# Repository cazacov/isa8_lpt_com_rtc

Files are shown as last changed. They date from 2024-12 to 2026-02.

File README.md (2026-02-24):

# ISA8 LPT COM RTC

An 8-bit ISA expansion card providing a parallel port, two serial ports, and a battery-backed real-time clock for retro PC/XT systems.

The card was designed with a help of GitHub Copilot.

## Prototype
See [prototype.md](./prototype.md) - Learn how to decode address, control RTC chip and design GAL firmware.
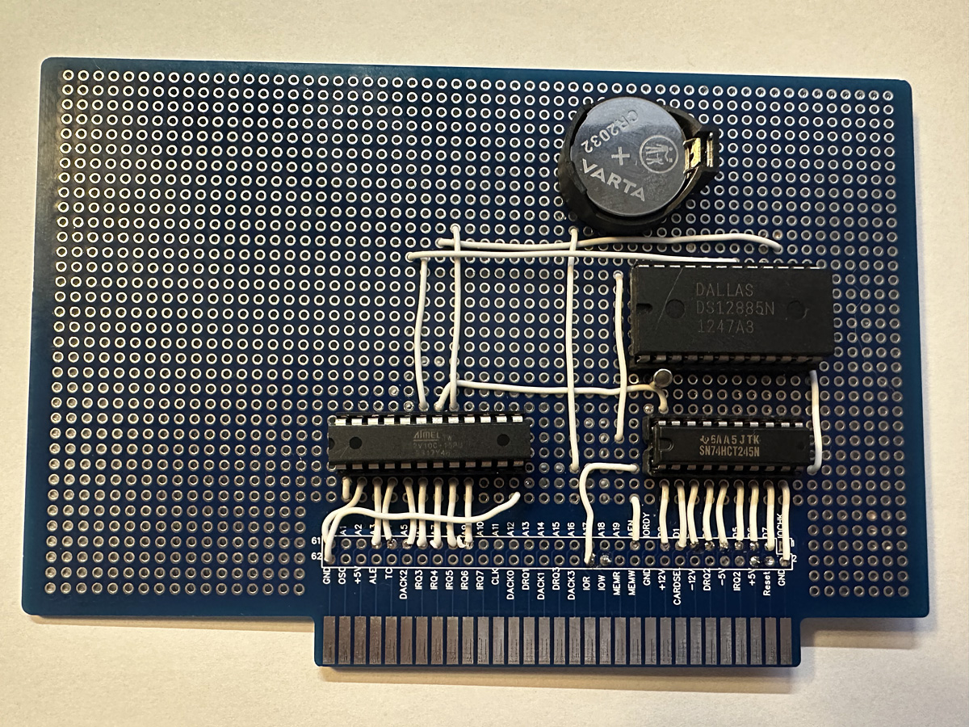
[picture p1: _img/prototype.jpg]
Prototype

Vibe soldering with LLM.

## Features

- **Parallel Port (PRN)** — UM82C11-C, DB-25 connector, Centronics-compatible
- **2 × Serial Port (COM)** — 16450/16550-compatible UARTs, RS-232 levels via GD75232N
- **Real-Time Clock (RTC)** — DS12885 with CR2032 battery backup and CMOS RAM
- **Single-chip address decoding** — ATF22V10 PLD, no additional logic gates
- **Fully jumper-configurable** — port addresses and IRQs
- **Socket-based device enable/disable** — devices disabled by removing chip from socket; 10k pull-up resistor network on data bus ensures clean 0xFF reads for empty sockets

## Target Systems

- IBM PC/XT and compatibles (8088/8086)
- Compatible with [8088 BIOS](https://github.com/skiselev/8088_bios)
- DOS and early Windows

## Design Specifications

### ISA Bus Interface

- 8-bit data bus (D0–D7)
- Standard ISA 8-bit (62-pin) edge connector
- +5 V, +12 V, −12 V power rails from bus

### Parallel Port (PRN)

- UM82C11-C printer adapter interface chip
- DB-25 connector, standard Centronics-compatible
- Configurable base address: 0x378 (LPT1) or 0x278 (LPT2)
- Configurable interrupt: IRQ7 or IRQ5
- Active-low chip select: PRN_CS#

### Serial Ports (UART)

Both ports use 16450/16550-compatible UARTs with RS-232 level shifting (GD75232N or equivalent). CS0 and CS1 are tied to GND; CS2 is the active-low chip select driven by the PLD.

| Port | Connector | Base Address Options | IRQ Options | CS Signal |
|---|---|---|---|---|
| COM1 | DB-9 | 0x3F8 or 0x2F8 | IRQ4 or IRQ3 | COM1_CS# |
| COM2 | 2×5 header | 0x3E8 or 0x2E8 | IRQ4 or IRQ3 | COM2_CS# |

### Real-Time Clock (RTC)

- DS12885 RTC chip with CMOS RAM for BIOS settings
- CR2032 battery backup
- Fixed I/O ports 0x70 (address) / 0x71 (data)
- Intel bus timing (MOT pin left unconnected; internal 20kΩ pull-down selects Intel mode)
- Configurable interrupt: IRQ2/9, IRQ5, IRQ6, or IRQ7
- IRQ polarity inversion: DS12885 IRQ output is active-low open-drain; an NPN transistor (Q1, 2N3904) with a 330Ω series current-limiting resistor converts it to the active-high signal expected by the ISA bus 8259A PIC (see [design.md](design.md) Section 6 for circuit details)
- On PC/XT (single 8259A), the IRQ2 jumper position triggers IRQ2 (INT 0Ah); on AT-class systems (cascaded 8259A), the same physical IRQ2 line is routed to the slave PIC as IRQ9 (INT 71h), which the BIOS redirects to INT 0Ah for compatibility
- Multiplexed address/data bus: CPU writes register address to port 0x70, then reads/writes data at port 0x71 (see [design.md](design.md) Section 5 for interface details, timing diagrams, and PLD equations)

### Oscillators

| Ref | Frequency | Purpose |
|-----|---|---|
| Y1 | 32.768 kHz | RTC crystal |
| Y2 | 1.8432 MHz | UART clock oscillator |

### Data Bus Buffering

A 74HCT245 bidirectional transceiver decouples all peripheral data pins from the ISA bus:

- **ISA side** (A1–A8, pins 2–9) — connected to ISA D0–D7
- **Card side** (B1–B8, pins 11–18) — connected to RTC, UART, and PRN data pins; 8×10k pull-up resistor network to VCC ensures defined HIGH state when no device drives the bus (empty sockets read as 0xFF)
- **DIR** — connected to IOR# (IOR#=0 → B-to-A read; IOR#=1 → A-to-B write)
- **G#** — active-low enable driven by ATF22V10

### Address Decoding

A single ATF22V10 PLD decodes all port addresses and generates chip-select signals for every peripheral, plus the bus buffer enable and the RTC address strobe. No additional logic gates are required. Jumper inputs to the PLD allow per-device address and enable configuration.

See [design.md](design.md) for detailed PLD equations, pin assignments, and CUPL source.

### Jumper Configuration

#### Address Selection (3-pin headers: VCC / signal / GND)

| Jumper | Cap 1-2 (HIGH) | Cap 2-3 (LOW) |
|---|---|---|
| J1 (COM1 Addr) | 0x3F8 (COM1) | 0x2F8 (COM2) |
| J3 (COM2 Addr) | 0x3E8 (COM3) | 0x2E8 (COM4) |
| J5 (PRN Addr) | 0x378 (LPT1) | 0x278 (LPT2) |

#### IRQ Selection (3-pin headers)

| Jumper | Position 1 | Position 2 |
|---|---|---|
| J2 (COM1 IRQ) | IRQ4 | IRQ3 |
| J4 (COM2 IRQ) | IRQ4 | IRQ3 |
| J6 (PRN IRQ) | IRQ7 | IRQ5 |
| J7 (RTC IRQ) | IRQ2/9 / IRQ5 / IRQ6 / IRQ7 (1×5 header) | — |

#### RTC CMOS Clear

J8 is a 2-pin header connected between DS12885 RCLR# (pin 21) and GND. The RCLR# pin has an internal pull-up inside the DS12885. Momentarily shorting J8 with a jumper cap (while the system is powered off) clears all CMOS RAM and RTC registers to defaults.

#### Device Enable/Disable

Devices are enabled/disabled by installing or removing the chip from its DIP socket. A 10k×8 pull-up resistor network on the 74HCT245 B-side ensures that empty sockets read as 0xFF, which is the expected response for absent I/O devices. Software detection (e.g., BIOS UART scratch register test) correctly identifies the device as absent.

The RTC is always enabled (no disable mechanism).

## Manufacturing Notes

- **Board thickness:** 1.6 mm
- **Copper weight:** 1 oz (35 μm)
- **Surface finish:** HASL or ENIG
- **Solder mask / silkscreen:** any color; white silkscreen on top
- **Components:** through-hole
- **Form factor:** standard ISA 8-bit card dimensions
- **Connectors:** bracket-mounted DB-25 and DE-9; CR2032 battery holder

## Getting Started

### Required Software

- [KiCad](https://www.kicad.org/) 9.0 or later
- [GALasm](https://github.com/daveho/GALasm) to compile firmware
- A PLD programmer (e.g. TL866II+) for the ATF22V10
- Git

### Opening the Project

1. Clone the repository
2. Open `KiCad/V2/ISA8_LPT_COM_RTC.kicad_pro` in KiCad
3. Schematic: `KiCad/V2/ISA8_LPT_COM_RTC.kicad_sch`
4. PCB layout: `KiCad/V2/ISA8_LPT_COM_RTC.kicad_pcb`

### Testing

1. Visually inspect for solder bridges; continuity-test power rails
2. Install card in an ISA slot
3. Verify I/O port addressing with DEBUG or a diagnostic utility
4. Test serial ports with a loopback plug or terminal program
5. Test parallel port with a printer or loopback connector
6. Verify RTC keeps time after power-off (battery backup)
7. Confirm interrupt operation for each device

## KiCad

Third party libraries should be stored in locations referenced with environment variables:
- **KICADLIB_SKISELEV** [Sergey Kiselev's library](https://github.com/skiselev/my_kicad_library)
- **KICADLIB_VICTOR** [Victor's (my) library](https://github.com/cazacov/VictorLib)

## Troubleshooting

| Symptom | Check |
|---|---|
| Card not detected | ISA slot seating, power rails |
| Address conflicts | Reconfigure base address jumpers, ensure ATF22V10 firmware is programmed properly |
| IRQ conflicts | Change IRQ jumper settings |
| RTC loses time | Replace CR2032 battery |
| Serial errors | Baud rate, RS-232 cable/levels |
| Parallel port issues | Cable, port mode |

## Project Files

| File | Description |
|---|---|
| `KiCad/V2/ISA8_LPT_COM_RTC.kicad_pro` | KiCad project |
| `KiCad/V2/ISA8_LPT_COM_RTC.kicad_sch` | Schematic |
| `KiCad/V2/ISA8_LPT_COM_RTC.kicad_pcb` | PCB layout |
| `design.md` | Implementation plan — PLD equations, pin maps, CUPL source |
| `pld/ISA8_DECODE.pld` | CUPL source for ATF22V10 |
| `pld/ISA8_DECODE.jed` | Compiled JEDEC fuse map |

## Datasheets

- [DS12885 / DS12C887A (RTC)](https://www.analog.com/media/en/technical-documentation/data-sheets/DS12885-DS12C887A.pdf)

## Version History

| Version | Notes |
|---|---|
| V2 | Current design iteration |
| V1 | Initial design (see `KiCad/V1/`) |

## Contributing

1. Document all schematic changes
2. Update PCB layout accordingly
3. Run DRC and ERC in KiCad
4. Update documentation as needed

## Credits

- [Sergey Kiselev's projects](https://github.com/skiselev)
- [Aitor Gómez García's RTC8088 project](https://github.com/spark2k06/RTC8088)

## License

MIT

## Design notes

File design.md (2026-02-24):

# ISA8 LPT COM RTC - Implementation Plan

## 1. ISA Bus Signals Used

| ISA Signal | Direction | Purpose |
|---|---|---|
| D0-D7 | Bidir | Data bus (active via 74245) |
| A0-A9 | In | Address bus (only A0-A9 needed, highest port 0x3F8 = 0b11_1111_1000; A2 also used for precise RTC decode) |
| AEN | In | DMA cycle indicator. Must be LOW for valid CPU I/O cycle |
| IOR# | In | I/O Read strobe (active low) |
| IOW# | In | I/O Write strobe (active low) |
| IRQ3-IRQ7 | Out | Interrupt request lines (active high) |

## 2. I/O Port Address Map

| Device | Option A (Default) | Option B | Address Range Size |
|---|---|---|---|
| COM1 | 0x3F8-0x3FF | 0x2F8-0x2FF | 8 bytes |
| COM2 | 0x3E8-0x3EF | 0x2E8-0x2EF | 8 bytes |
| PRN  | 0x378-0x37F (LPT1) | 0x278-0x27F (LPT2) | 8 bytes |
| RTC | 0x70-0x71 | (fixed) | 2 bytes |

### Address Bit Patterns (A9..A0)

```
COM1 @ 0x3F8:  11 1111 1xxx    COM1 @ 0x2F8:  10 1111 1xxx
COM2 @ 0x3E8:  11 1110 1xxx    COM2 @ 0x2E8:  10 1110 1xxx
PRN   @ 0x378:  11 0111 1xxx    PRN   @ 0x278:  10 0111 1xxx
RTC   @ 0x070:  00 0111 00 0x   (fixed, no jumper; A2 checked by PLD)
```

Note: `x` bits are don't-care for chip-select (decoded internally by each device via A0-A2). For the RTC, A0 and A2 are checked by the PLD; A1 is not checked (mirroring at 0x72/0x73 only — unused addresses on any standard PC).

## 3. Jumper Design

### 3.1 Jumper Inputs to ATF22V10

Instead of feeding raw address lines and muxing them inside the PLD, use jumpers to route one of two address lines to a single PLD input. This minimizes PLD pin usage.

The key observation: for each device pair, only **one address bit** changes between Option A and Option B — and that bit is always **A8**:

| Device | Option A | Option B | Differing Bit |
|---|---|---|---|
| COM1 | 0x3F8 (A8=1) | 0x2F8 (A8=0) | A8 |
| COM2 | 0x3E8 (A8=1) | 0x2E8 (A8=0) | A8 |
| PRN | 0x378 (A8=1) | 0x278 (A8=0) | A8 |

All three devices have A9=1 for both address options. Each device needs its own jumper input to the PLD for independent address configuration.

**Approach: one jumper bit per device fed into the PLD.**

- **J_COM1**: 1-bit jumper (HIGH = 0x3F8, LOW = 0x2F8)
- **J_COM2**: 1-bit jumper (HIGH = 0x3E8, LOW = 0x2E8)
- **J_PRN**: 1-bit jumper (HIGH = 0x378, LOW = 0x278)

These jumper signals connect directly to ATF22V10 inputs. The PLD equations incorporate them.

### 3.2 IRQ Selection Jumpers

IRQ routing does NOT go through the PLD. Use simple 3-pin jumper headers connecting each device's IRQ output to the selected ISA IRQ line.

| Jumper | Position 1 | Position 2 | Notes |
|---|---|---|---|
| J_IRQ_COM1 | IRQ4 | IRQ3 | Standard COM1=IRQ4, COM2=IRQ3 |
| J_IRQ_COM2 | IRQ4 | IRQ3 | Standard COM3=IRQ4, COM4=IRQ3 |
| J_IRQ_PRN | IRQ7 | IRQ5 | Standard LPT1=IRQ7, LPT2=IRQ5 |
| J_IRQ_RTC | IRQ2/9 / IRQ5 / IRQ6 / IRQ7 | — | 5-pin header, jumper selects one of 4 |

For the RTC IRQ (4 choices: IRQ2/9, IRQ5, IRQ6, IRQ7), use a 1×5 pin header:
```
Pin 1: RTC_IRQ_OUT (from Q1 collector via R4, active high — inverted from DS12885)
Pin 2: IRQ2 (= IRQ9 on AT-class machines via cascade)
Pin 3: IRQ5
Pin 4: IRQ6
Pin 5: IRQ7
```
A single jumper wire connects Pin 1 to one of Pins 2–5.

**Note:** On PC/XT systems (single 8259A), the IRQ2 pin triggers IRQ2 (INT 0Ah) directly. On AT-class systems (cascaded 8259A), the same physical IRQ2 line is routed to the slave PIC IR1 input, generating IRQ9 (INT 71h). The AT BIOS redirects INT 71h → INT 0Ah for compatibility.

### 3.3 Jumper Summary Table

| Jumper | Type | Pins | Function |
|---|---|---|---|
| J1 (COM1 Addr) | 3-pin header | 1=VCC, 2=J_COM1, 3=GND | Cap 1-2: 0x3F8 (COM1), Cap 2-3: 0x2F8 (COM2) |
| J2 (COM1 IRQ) | 3-pin header | 1=IRQ4, 2=COM1_IRQ, 3=IRQ3 | Select IRQ |
| J3 (COM2 Addr) | 3-pin header | 1=VCC, 2=J_COM2, 3=GND | Cap 1-2: 0x3E8 (COM3), Cap 2-3: 0x2E8 (COM4) |
| J4 (COM2 IRQ) | 3-pin header | 1=IRQ4, 2=COM2_IRQ, 3=IRQ3 | Select IRQ |
| J5 (PRN Addr) | 3-pin header | 1=VCC, 2=J_PRN, 3=GND | Cap 1-2: 0x378 (LPT1), Cap 2-3: 0x278 (LPT2) |
| J6 (PRN IRQ) | 3-pin header | 1=IRQ7, 2=PRN_IRQ, 3=IRQ5 | Select IRQ |
| J7 (RTC IRQ) | 1×5 header | 1=RTC_IRQ_OUT, 2=IRQ2/9, 3=IRQ5, 4=IRQ6, 5=IRQ7 | Jumper wire Pin1 to one of Pin2–5 |
| J8 (CMOS Clear) | 2-pin header | 1=RCLR#, 2=GND | Short momentarily (power off) to clear CMOS RAM |

### 3.4 Device Enable/Disable

Devices are enabled/disabled by installing or removing the chip from its DIP socket. A 10k×8 pull-up resistor network (RN1) on the 74HCT245 B-side ensures empty sockets read as 0xFF. Software detection (e.g., BIOS UART scratch register test) correctly identifies absent devices. No PLD input pins or jumpers are needed for device enable/disable.

**Address jumper wiring (3-pin header):**

All three address jumpers (J1, J3, J5) follow the same scheme:

```
  Pin 1 = VCC
  Pin 2 = J_xxx (to PLD input, 10k pull-down to GND)
  Pin 3 = GND
```
- Cap on 1-2: signal = HIGH → Option A (higher address)
- Cap on 2-3: signal = LOW → Option B (lower address)
- No cap: signal = LOW (pull-down) → Option B (default)

The PLD equation uses XNOR(A8, J_xxx) to check whether the bus address bit A8 matches the jumper setting.

## 4. ATF22V10 Pin Assignment

### 4.1 ATF22V10C Pinout (24-pin DIP/PLCC)

- Pins 1, 2-11: Inputs (pin 1 is clock/input, pins 2-11 are dedicated inputs)
- Pins 14-23: I/O (can be output or feedback)
- Pin 12: GND
- Pin 24: VCC

### 4.2 Pin Assignment

| ATF22V10 Pin | Direction | Signal | Purpose |
|---|---|---|---|
| 1 | Input | A0 | Address bit 0 (for RTC decode: port 0x70 vs 0x71) |
| 2 | Input | A2 | Address bit 2 (for precise RTC decode, eliminates 0x74-0x77 mirroring) |
| 3 | Input | A3 | Address bit 3 |
| 4 | Input | A4 | Address bit 4 |
| 5 | Input | A5 | Address bit 5 |
| 6 | Input | A6 | Address bit 6 |
| 7 | Input | A7 | Address bit 7 |
| 8 | Input | A8 | Address bit 8 |
| 9 | Input | A9 | Address bit 9 |
| 10 | Input | IOR# | ISA I/O Read strobe (active low), used for RTC_DS# generation |
| 11 | Input | IOW# | ISA I/O Write strobe (active low), used for RTC_AS and RTC_WR# generation |
| 12 | — | GND | Ground |
| 13 | Input | AEN | DMA indicator (active high = DMA, must be 0 for I/O) |
| 14 | Output | COM1_CS# | COM1 chip select (active low) |
| 15 | Output | COM2_CS# | COM2 chip select (active low) |
| 16 | Output | PRN_CS# | PRN chip select (active low) |
| 17 | Output | RTC_WR# | RTC write strobe (active low) → DS12885 WR# |
| 18 | Output | BUF_EN# | 74245 enable (active low) |
| 19 | Output | RTC_AS | DS12885 Address Strobe (active high, gated with IOW# + address decode) |
| 20 | Output | RTC_DS# | RTC data strobe (active low) → DS12885 DS# |
| 21 | Input | J_COM1 | Jumper: COM1 address select (1=0x3F8, 0=0x2F8) |
| 22 | Input | J_COM2 | Jumper: COM2 address select (1=0x3E8, 0=0x2E8) |
| 23 | Input | J_PRN | Jumper: PRN address select (1=0x378, 0=0x278) |
| 24 | — | VCC | +5V |

**Note:** A1 is not needed for chip-select decode — it is decoded internally by each peripheral (UART uses A0-A2, PRN uses A0-A2). A0 and A2 are on dedicated input pins 1–2 for compact address bus routing. A2 is checked by the PLD for the RTC address decode to prevent mirroring at 0x74-0x77 (the slave 8259A range on AT-class machines); mirroring at 0x72-0x73 (A1 unchecked) is harmless since those addresses are unused on any standard PC. IOR# and IOW# are on dedicated input pins 10–11 for RTC strobe generation. AEN is on I/O pin 13 (configured as input). All three address jumpers (J_COM1, J_COM2, J_PRN) are grouped on adjacent I/O pins 21–23 for a clean jumper layout. All 24 pins are assigned — no spare pins remain. Devices are enabled/disabled by installing or removing chips from sockets.

## 5. DS12885 RTC Interface to ISA Bus

### 5.1 Bus Mode Selection

Intel bus timing mode is selected by leaving MOT pin unconnected (internal 20k pull-down to GND).

### 5.2 Signal Connections

| DS12885 Pin | Signal | ISA / Board Connection |
|---|---|---|
| MOT | Bus mode | Leave unconnected (pulled low internally → Intel mode) |
| AD0-AD7 | Mux Addr/Data | Connected to card-side data bus (74245 B-side). These are shared address AND data lines. |
| CS | Chip select | Tie to GND (always selected — access is controlled by PLD-qualified strobes) |
| AS | Address strobe | RTC_AS from ATF22V10 — active-high, gated with IOW# and address decode (see below) |
| DS# | Data strobe | RTC_DS# from ATF22V10 — active-low, fires only during IN from port 0x71 |
| WR# | Write strobe | RTC_WR# from ATF22V10 — active-low, fires only during OUT to port 0x71 |
| RESET | Reset | Tie to VCC (per datasheet: allows power-fail transitions without clearing control registers) |
| IRQ | Interrupt out | Open-drain, inverted via NPN transistor (Q1) to active-high; output via R4 (330Ω) to jumper J7 selecting IRQ2/9, IRQ5, IRQ6, or IRQ7 (see Section 6) |
| SQW | Square wave | Leave unconnected or route to test point |
| X1, X2 | Crystal | 32.768 kHz crystal (Y1) |
| VCC | Power | +5V from ISA bus |
| VBAT | Backup battery | CR2032 (3V) via battery holder |
| RCLR | RAM clear | Internal pull-up; 2-pin header J8 to GND for manual CMOS clear |

### 5.3 Multiplexed Address/Data Bus — Address Latch Mechanism

The DS12885 uses a **multiplexed** address/data bus (AD0-AD7). The CPU first writes a register address to port 0x70, then reads/writes data at port 0x71:

- **Port 0x70 (A0=0):** AS pulses HIGH → DS12885 latches AD0–AD7 as the internal register address.
- **Port 0x71 (A0=1):** AS stays LOW → normal data read/write to the previously addressed register.

**Implementation:** `RTC_AS = !AEN & !IOW & !A0 & address_decode` — the AS signal is fully qualified with the IOW# strobe and RTC address decode inside the PLD. Per the DS12885 datasheet, address latching via AS occurs regardless of CS state (*"Bus cycles that take place without asserting CS will latch addresses, but no access occurs"*). This means a naive `AS = !A0` would corrupt the address latch during every non-RTC bus cycle (instruction fetches, other I/O), because AS would toggle and re-latch whatever residual charge remains on the floating AD0-AD7 lines. By gating AS with IOW# and address decode, the latch opens ONLY during the IOW# pulse of an `OUT 70h` instruction, guaranteeing valid data capture and preventing corruption between bus cycles.

### 5.4 Intel Mode Timing Summary

For a **write to port 0x70** (set RTC register address):
1. CPU puts 0x70 on address bus, AEN=0
2. ATF22V10 asserts BUF_EN# low. RTC_AS stays LOW (IOW# not yet active). RTC_WR# stays HIGH. DS12885 CS# is permanently GND.
3. CPU drives data (register address 0x00-0x7F) on D0-D7 → through 74245 → AD0-AD7
4. IOW# goes LOW → ATF22V10 asserts RTC_AS HIGH (address match + A0=0 + IOW# active) → DS12885 AS goes HIGH → address latch becomes **transparent** → AD0-AD7 value (register address) flows through to the internal register address. RTC_WR# stays HIGH (A0=0, not a data write).
5. IOW# returns HIGH → ATF22V10 deasserts RTC_AS → AS **falls** → address latch **freezes**, capturing the register address that was present on AD0-AD7
6. Bus cycle ends. Between bus cycles, RTC_AS stays LOW — the address latch is frozen and cannot be corrupted by intervening instruction fetches or other bus activity

For a **read from port 0x71** (read RTC register data):
1. CPU puts 0x71 on address bus, AEN=0
2. ATF22V10 asserts BUF_EN# low. AS stays LOW (A0=1) — address latch **stays frozen** with the previously set register address
3. IOR# goes LOW → ATF22V10 asserts RTC_DS# LOW (address match + A0=1 + IOR# active) → DS12885 DS# goes LOW → DS12885 drives register data onto AD0-AD7
4. 74245 direction = B→A (IOR# = 0 → DIR = 0) → data flows to ISA D0-D7
5. CPU reads data; IOR# goes HIGH → RTC_DS# goes HIGH → DS12885 releases bus

For a **write to port 0x71** (write RTC register data):
1. Same addressing as read — AS=0, address latch frozen
2. CPU drives write data on D0-D7 → through 74245 → AD0-AD7
3. IOW# goes LOW → ATF22V10 asserts RTC_WR# LOW (address match + A0=1 + IOW# active) → DS12885 WR# goes LOW
4. IOW# goes HIGH → RTC_WR# goes HIGH → WR# rising edge → DS12885 latches AD0-AD7 as write data

### 5.5 Intel Mode Timing Diagram

**Write to port 0x70 — Set RTC register address:**

```
  Signals during OUT 0x70, <reg_addr>:

  A0 ──────┐                              ┌─────
           └──────────────────────────────┘
  CS# ──┐                                ┌────
        └────────────────────────────────┘
  R/W ────────────┐             ┌─────────────
  (IOW#)          └─────────────┘
  AD0-7           ╔═══════reg_addr════════╗
  (via 74245)     ╚═══════════════════════╝
  AS ───────────────┐       ┌──────────────────
  (RTC_AS)          └───────┘
                    ▲       ▲
                    │ IOW#  │ IOW# returns HIGH
                    │ goes  │ → AS falls
                    │ LOW   │ → latch freezes
                    │ → AS  │   reg_addr captured
                    │ HIGH  │
                    │ latch │
                    │ opens │
```

### 5.6 Timing Compliance (from DS12885 AC specifications)

| Parameter | Symbol | Min | Our design meets? |
|---|---|-----|---|
| AS high pulse width | PWASH | 60 ns | Yes — AS=HIGH for IOW# pulse width (~350 ns on ISA) |
| Address valid before AS fall | tASL | 30 ns | Yes — data bus is stable before IOW# returns HIGH |
| Address hold after AS fall | tAHL | 10 ns | Yes — 74245 disable propagates through PLD (~15 ns), bus hold capacitance maintains data |
| AS fall to DS#/WR# assertion | tASED | 40 ns | Yes — AS falls at end of port 0x70 cycle; DS#/WR# asserts at start of port 0x71 cycle (≥200 ns apart at 4.77 MHz) |
| CS setup before DS# or WR# | tCS | 20 ns | Yes — CS# is permanently GND; always satisfied |

### 5.7 Address Latch Integrity Between Bus Cycles

Since RTC_AS is gated with IOW# and the full RTC address decode, the DS12885 address latch opens **only** during the IOW# pulse of an `OUT 70h` instruction. Between bus cycles, RTC_AS stays LOW and the address latch remains frozen — no corruption is possible.

This is critical because the DS12885 datasheet states that AS-triggered address latching occurs regardless of CS state. A simpler approach like `AS = !A0` would toggle the latch during every bus cycle, re-latching whatever residual charge remains on the floating AD0-AD7 lines — an unreliable scheme that depends on bus capacitance retention across multiple instruction fetch cycles.

## 6. RTC IRQ Polarity Inversion

The DS12885 IRQ output is **active-low, open-drain** — it pulls LOW to assert an interrupt and floats (high-impedance) when idle. ISA bus IRQ lines (IRQ2–7) are **active-high, edge-triggered** — the 8259A PIC requires a LOW→HIGH transition to recognize an interrupt. An NPN transistor inverts the polarity.

### Circuit

RTC IRQ Polarity Inversion — NPN Inverter

### Operation

| DS12885 state | IRQ pin | NPN Q1 | Q1 collector | ISA IRQ line | Result |
|---|---|---|---|---|---|
| No interrupt | HIGH (pull-up R1) | ON (saturated) | LOW (~0.2V) | LOW (idle) | Correct — no interrupt |
| Interrupt active | LOW (open-drain pulls down) | OFF | HIGH (pull-up R3) | HIGH via R4 | Correct — interrupt asserted |

### Component Values

| Ref | Value | Purpose |
|---|---|---|
| R1 | 4.7kΩ | Pull-up for DS12885 open-drain IRQ output |
| R2 | 4.7kΩ | NPN base current limiter; $I_B = (5 - 0.7) / 4.7\text{k} \approx 0.9\text{mA}$ — sufficient to saturate |
| R3 | 4.7kΩ | Collector pull-up to VCC; provides active-high output when Q1 is OFF |
| R4 | 330Ω | Series current limiter between collector and ISA IRQ line — protects against bus contention if another card accidentally drives the same IRQ |
| Q1 | 2N3904 | NPN transistor (TO-92); any general-purpose NPN (BC547, 2N2222) works |

### Contention Protection

R4 (330Ω) limits current if another ISA card drives the same IRQ line HIGH while Q1 is ON (sinking to GND). Worst case: $(3.5 - 0.2)\text{V} / 330\Omega \approx 10\text{mA}$ — well within safe limits for both the NPN and the other card's output stage.

### Signal Integrity

- **HIGH delivery** (interrupt active, Q1 OFF): 4.7kΩ pull-up through 330Ω to the 8259A input (~40µA draw). Voltage drop across R4 ≈ 0.013V — negligible. ISA IRQ sees ~4.9V, well above $V_{IH} = 2.0\text{V}$.
- **LOW delivery** (idle, Q1 ON): $V_{CE(sat)} \approx 0.2\text{V}$ plus negligible drop across R4. ISA IRQ sees ~0.2V, well below $V_{IL} = 0.8\text{V}$.

### Behavioral Consistency with UART/PRN IRQ Outputs

The 16450/16550 UART INTRPT and UM82C11 IRQ outputs are totem-pole (push-pull, active-high). The NPN inverter produces identical bus behavior: actively drives LOW when idle, drives HIGH when interrupting. This is standard for ISA 8-bit cards and consistent across all four device IRQ outputs on this card.

## 7. 74245 Bus Buffer

### 7.1 Connections

| 74245 Pin | Signal | Connection |
|---|---|---|
| A1-A8 (pins 2-9) | ISA D0-D7 | ISA bus data lines |
| B1-B8 (pins 11-18) | Card D0-D7 | COM1, COM2, PRN data pins, DS12885 AD0-AD7 |
| DIR (pin 1) | Direction | Connected to IOR# from ISA bus |
| G# (pin 19) | Enable | BUF_EN# from ATF22V10 |

### 7.2 Direction Logic

- IOR# = 0 (I/O read active): DIR = 0 → B-to-A (device → ISA bus)
- IOR# = 1 (idle or I/O write): DIR = 1 → A-to-B (ISA bus → device)

### 7.3 Enable Logic

G# (BUF_EN#) is active low. The 74245 is enabled only when a device on this card is being addressed, preventing bus conflicts with other ISA cards.

## 8. Bill of Materials (Logic Section)

| Ref | Component | Package | Qty | Purpose |
|---|---|---|---|---|
| U1 | ATF22V10C-15PU | DIP-24 | 1 | Address decode PLD |
| U2 | 74HCT245 | DIP-20 | 1 | Bidirectional bus buffer |
| U3 | DS12885 | DIP-24 / PLCC-28 | 1 | Real-time clock |
| U4 | 16C450 or 16C550 | DIP-40 | 2 | UART (COM1, COM2) |
| U5 | UM82C11-C | DIP-40 | 1 | Parallel port controller |
| U6 | GD75232N | DIP-20 | 1-2 | RS-232 level shifter |
| Y1 | 32.768 kHz crystal | HC49 | 1 | RTC oscillator |
| Y2 | 1.8432 MHz oscillator | DIP-8/14 | 1 | UART clock |
| BT1 | CR2032 holder | Through-hole | 1 | RTC battery backup |
| RN1 | 10k×8 SIP resistor network | SIP-9 | 1 | Pull-up for 74HCT245 B-side (active device side) |
| Q1 | 2N3904 | TO-92 | 1 | NPN transistor — RTC IRQ polarity inverter |
| R1 | 4.7k resistor | Axial | 1 | Pull-up for DS12885 IRQ (open-drain) |
| R2 | 4.7k resistor | Axial | 1 | NPN base current limiter |
| R3 | 4.7k resistor | Axial | 1 | NPN collector pull-up |
| R4 | 330Ω resistor | Axial | 1 | Series current limiter — contention protection |
| R5-R7 | 10k resistor | Axial | 3 | Pull-down for J_xxx addr jumpers |
| JP1-JP7 | Pin headers | 2.54mm | Various | Jumper configuration headers |

## 9. Schematic Block Diagram

```
                                    ISA 8-bit Bus (edge connector)
===============================================================================
| D0-D7         IOR#  IOW#     A0-A2        A3-A9         AEN                 |
===============================================================================
    ^             |     |         |            |            |
    |             |     |         |            |            |
    |             |     |         |            |            |
    v             v     v         v            v            v
+------------+    |     |         |      +----------------------------------------------+     +----------------------------+
| 74HCT245   |    |     |         |      |            ATF22V10                          |     |    Address Jumpers         |
|            |    |     |         |      |                                              |     |----------------------------|
| Side A     |    |     |         +----->|                                              |     | J1: 0x3F8/0x2F8 (COM1)    |
|            |    |     |         |      |                                              |<----+ J3: 0x3E8/0x2E8 (COM2)    |
|            |    |     +--------------->|                                              |     | J5: 0x378/0x278 (PRN)     |
|            |    |               |      |                                              |     +----------------------------+
|            |<---+--------------------->|                                              |
|            |                    |      |                                              |
| Side B     |<--- BUF_EN# --------------+                                              |
|            |                    |      |                                              |
+------------+                    |      +----------------------------------------------+
    ^                             |          |            |            |            |
    |                             |          v            v            v            v
    |                             |     RTC signals    COM1_CS#     COM2_CS#     PRN_CS# 
    |                             |
    |   (buffered D0-D7)    A0-A2 (to devices)
    |
    +--- (continues to devices below...)
```

## 10. Implementation Steps

1. **Create KiCad schematic** with all components
2. **Program ATF22V10** with CUPL equations using a programmer (e.g., TL866II+)
3. **Verify address decode** with logic analyzer before populating all ICs
4. **PCB layout** following standard ISA card dimensions (XT 8-bit: 4.8" x 3.7" approx)
5. **Test each subsystem** independently (RTC first, then UARTs, then PRN)

## 11. Design Notes and Caveats

- The ATF22V10C-15PU (15ns) is fast enough for ISA bus timing (ISA bus cycle ~500ns minimum).
- All address jumper pull-down resistors (10k) ensure a defined state when no jumper cap is installed (defaults to Option B / lower address).
- Devices are enabled/disabled by installing or removing chips from their sockets. A 10k×8 SIP pull-up network on the 74HCT245 B-side keeps all data lines at defined HIGH levels when a socket is empty, preventing bus contention.
- The DS12885 IRQ output is open-drain — it MUST have an external pull-up resistor (4.7k to VCC).
- UART IRQ outputs may need to be open-collector/drain if sharing IRQ lines. Check the specific UART chip datasheet.
- The 74HCT245 variant (not 74HC245) is recommended for proper TTL-level compatibility with the ISA bus.
- CR2032 battery: connect positive terminal to DS12885 VBAT, negative to GND. Add a series diode (1N4148) or Schottky diode to prevent reverse charging (optional, DS12885 is UL recognized for this).

## 12. ATF22V10 Chip Logic — Detailed Analysis

### 12.1 XNOR Address Matching

For each configurable device (COM1, COM2, PRN), the two alternative base addresses differ only in A8. The PLD uses XNOR(A8, J_xxx) to check whether the bus address matches the jumper setting:

$$\text{A8\_MATCH} = \text{A8} \odot \text{J\_xxx} = (\text{A8} \cdot \text{J\_xxx}) + (\overline{\text{A8}} \cdot \overline{\text{J\_xxx}})$$

Since the ATF22V10 cannot express XNOR as a single gate, each chip-select equation expands into two product terms (one for A8=1∧J=1, one for A8=0∧J=0). The remaining address bits (A9, A7–A3) are checked against fixed expected values. Every equation also requires AEN=0 (not a DMA cycle).

### 12.2 PLD Equations

**COM1** (0x3F8 or 0x2F8 — fixed bits: A9=1, A7–A3=11111):

```
/COM1 = /AEN * A9 *  A8 *  JCOM1 * A7 * A6 * A5 * A4 * A3
       + /AEN * A9 * /A8 * /JCOM1 * A7 * A6 * A5 * A4 * A3
```

**COM2** (0x3E8 or 0x2E8 — same as COM1 but A4=0):

```
/COM2 = /AEN * A9 *  A8 *  JCOM2 * A7 * A6 * A5 * /A4 * A3
       + /AEN * A9 * /A8 * /JCOM2 * A7 * A6 * A5 * /A4 * A3
```

**PRN** (0x378 or 0x278 — same structure but A7=0):

```
/PRN = /AEN * A9 *  A8 *  JPRN * /A7 * A6 * A5 * A4 * A3
     + /AEN * A9 * /A8 * /JPRN * /A7 * A6 * A5 * A4 * A3
```

**RTC Write Strobe** (port 0x71 write — DS12885 WR#, 1 product term):

```
/RTC_WR = /AEN * /IOW * A0 * /A2 * /A9 * /A8 * /A7 * A6 * A5 * A4 * /A3
```

**BUFEN** — logical OR of all chip-select conditions. The CUPL source references the output signal names (`COM1_CS # COM2_CS # ...`), and the compiler expands them inline into the full product-term equations (7 terms total ≤ 16 available). This avoids pin-feedback delay and ensures BUF_EN# asserts simultaneously with the chip-select outputs, both with a single PLD propagation delay from input change:

```
/BUFEN = /AEN * A9 *  A8 *  JCOM1 * A7 * A6 * A5 * A4 * A3
       + /AEN * A9 * /A8 * /JCOM1 * A7 * A6 * A5 * A4 * A3
       + /AEN * A9 *  A8 *  JCOM2 * A7 * A6 * A5 * /A4 * A3
       + /AEN * A9 * /A8 * /JCOM2 * A7 * A6 * A5 * /A4 * A3
       + /AEN * A9 *  A8 *  JPRN   * /A7 * A6 * A5 * A4 * A3
       + /AEN * A9 * /A8 * /JPRN   * /A7 * A6 * A5 * A4 * A3
       + /AEN * /A2 * /A9 * /A8 * /A7 * A6 * A5 * A4 * /A3
```

**RTC_AS** — address strobe for DS12885, gated with IOW# and full RTC address decode. Goes HIGH only during a write to port 0x70 (IOW# active, A0=0, address matches). This ensures the address latch opens exclusively during the IOW# pulse of `OUT 70h`, preventing corruption between bus cycles:

```
RTC_AS = /AEN * /IOW * /A0 * /A2 * /A9 * /A8 * /A7 * A6 * A5 * A4 * /A3
```

**RTC Data Strobe** (port 0x71 read — DS12885 DS#, 1 product term):

```
/RTC_DS = /AEN * /IOR * A0 * /A2 * /A9 * /A8 * /A7 * A6 * A5 * A4 * /A3
```

### 12.3 Product Term Budget

| Output Pin | Signal | Available PTs | Used PTs | Utilization |
|---|---|---|---|---|
| 14 | /COM1 | 8 | 2 | 25% |
| 15 | /COM2 | 10 | 2 | 20% |
| 16 | /PRN | 12 | 2 | 17% |
| 17 | /RTC_WR | 16 | 1 | 6% |
| 18 | /BUFEN | 16 | 7 | 44% |
| 19 | RTC_AS | 14 | 1 | 7% |
| 20 | /RTC_DS | 12 | 1 | 8% |
| 21 | input (J_COM1) | — | 0 | — |
| 22 | input (J_COM2) | — | 0 | — |
| 23 | input (J_PRN) | — | 0 | — |

Total: **16 product terms** used, substantial headroom on all pins.

### 12.4 CUPL Source

```cupl
Name     ISA8_DECODE;
PartNo   01;
Date     2026-02-14;
Designer VK;
Company  ;
Assembly ;
Location ;
Device   g22v10;

/* Inputs */
Pin 1  = A0;    /* ISA address bit 0 (RTC port 0x70 vs 0x71) */
Pin 2  = A2;    /* ISA address bit 2 (precise RTC decode) */
Pin 3  = A3;
Pin 4  = A4;
Pin 5  = A5;
Pin 6  = A6;
Pin 7  = A7;
Pin 8  = A8;
Pin 9  = A9;
Pin 10 = IOR;   /* ISA IOR# (active low) */
Pin 11 = IOW;   /* ISA IOW# (active low) */
Pin 13 = AEN;   /* ISA AEN (DMA indicator) */

/* Address jumpers on I/O pins (configured as inputs) */
Pin 21 = J_COM1;
Pin 22 = J_COM2;

Pin 23 = J_PRN;

/* Outputs (active-low) */
Pin 14 = !COM1_CS;
Pin 15 = !COM2_CS;
Pin 16 = !PRN_CS;
Pin 17 = !RTC_WR;
Pin 18 = !BUF_EN;
Pin 19 = RTC_AS;
Pin 20 = !RTC_DS;

/* COM1: 0x3F8 or 0x2F8 — differ in A8 */
/* Common: A9=1, A7=1, A6=1, A5=1, A4=1, A3=1 */
COM1_CS = !AEN
         & A9 & (A8 $ !J_COM1) & A7 & A6 & A5 & A4 & A3;

/* COM2: 0x3E8 or 0x2E8 — differ in A8 */
/* Common: A9=1, A7=1, A6=1, A5=1, A4=0, A3=1 */
COM2_CS = !AEN
         & A9 & (A8 $ !J_COM2) & A7 & A6 & A5 & !A4 & A3;

/* PRN: 0x378 or 0x278 — differ in A8 */
/* Common: A9=1, A7=0, A6=1, A5=1, A4=1, A3=1 */
PRN_CS = !AEN
       & A9 & (A8 $ !J_PRN) & !A7 & A6 & A5 & A4 & A3;

/* RTC Write Strobe: drives DS12885 WR# (Intel mode) */
/* Fires during OUT to port 0x71 (A0=1, data register access) */
/* DS12885 CS# is tied to GND — access controlled by PLD-qualified strobes */
RTC_WR = !AEN & !IOW & A0 & !A2 & !A9 & !A8 & !A7 & A6 & A5 & A4 & !A3;

/* Buffer enable: active when any device address range is on the bus */
BUF_EN = COM1_CS # COM2_CS # PRN_CS
       # (!AEN & !A2 & !A9 & !A8 & !A7 & A6 & A5 & A4 & !A3);

/* RTC Address Strobe: drives DS12885 AS (Intel mode) */
/* Goes HIGH only during OUT 70h (IOW# active, A0=0, RTC address match) */
/* Prevents address latch corruption between bus cycles */
RTC_AS = !AEN & !IOW & !A0 & !A2 & !A9 & !A8 & !A7 & A6 & A5 & A4 & !A3;

/* RTC Data Strobe: drives DS12885 DS# (Intel mode) */
/* Fires during IN from port 0x71 (A0=1, data register access) */
RTC_DS = !AEN & !IOR & A0 & !A2 & !A9 & !A8 & !A7 & A6 & A5 & A4 & !A3;
```

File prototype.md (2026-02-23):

# ISA8 Prototype Board - Test RTC signals decoding

## Goal

Minimal ISA 8-bit card to validate:
1. ATF22V10 address decode logic (same firmware as full board)
2. 74HCT245 bus buffering
3. DS12885 RTC operation at ports 0x70/0x71

UART and PRN chips are not populated. Their ATF22V10 inputs are tied to safe defaults;
their ATF22V10 outputs are left unconnected.

---

## 1. Components

| Ref | Component | Package | Qty | Notes |
|---|---|---|---|---|
| U1 | ATF22V10C-15PU | DIP-24 | 1 | Address decode (full firmware) |
| U2 | 74HCT245 | DIP-20 | 1 | Bus buffer |
| U3 | DS12885 | DIP-24 | 1 | Real-time clock |
| Y1 | 32.768 kHz crystal | HC49 | 1 | RTC oscillator (6 pF load) |
| BT1 | CR2032 holder + cell | Through-hole | 1 | RTC battery backup |
| J1 | ISA 8-bit edge connector | 62-pin (2x31) | 1 | Bus interface |
| JP1 | 1x4 pin header | 2.54 mm | 1 | RTC IRQ select |
| R1 | 4.7k resistor | Axial | 1 | Pull-up for DS12885 IRQ (open-drain). Optional if IRQ not used. |
| C1 | 100 nF ceramic | Axial/radial | 1 | Bypass cap, ATF22V10 |
| C2 | 100 nF ceramic | Axial/radial | 1 | Bypass cap, 74HCT245 |
| C3 | 100 nF ceramic | Axial/radial | 1 | Bypass cap, DS12885 |
| C4 | 10 uF electrolytic | Radial | 1 | Bulk decoupling, VCC |

---

## 2. ISA Bus Signals Used

Only the subset of ISA bus signals needed for RTC operation:

| ISA Pin | Signal | Direction | Connection |
|---|---|---|---|
| A9 | D0 | Bidir | 74HCT245 pin 2 (A1) |
| A8 | D1 | Bidir | 74HCT245 pin 3 (A2) |
| A7 | D2 | Bidir | 74HCT245 pin 4 (A3) |
| A6 | D3 | Bidir | 74HCT245 pin 5 (A4) |
| A5 | D4 | Bidir | 74HCT245 pin 6 (A5) |
| A4 | D5 | Bidir | 74HCT245 pin 7 (A6) |
| A3 | D6 | Bidir | 74HCT245 pin 8 (A7) |
| A2 | D7 | Bidir | 74HCT245 pin 9 (A8) |
| A31 | A0 | In | ATF22V10 pin 1 |
| A30 | A1 | In | (not used — no connection) |
| A29 | A2 | In | ATF22V10 pin 2 |
| A28 | A3 | In | ATF22V10 pin 3 |
| A27 | A4 | In | ATF22V10 pin 4 |
| A26 | A5 | In | ATF22V10 pin 5 |
| A25 | A6 | In | ATF22V10 pin 6 |
| A24 | A7 | In | ATF22V10 pin 7 |
| A23 | A8 | In | ATF22V10 pin 8 |
| A22 | A9 | In | ATF22V10 pin 9 |
| B13 | IOW# | In | ATF22V10 pin 11 |
| B14 | IOR# | In | ATF22V10 pin 10, 74HCT245 pin 1 (DIR) |
| A11 | AEN | In | ATF22V10 pin 13 |
| B21 | IRQ7 | Out | JP1 option |
| B22 | IRQ6 | Out | JP1 option |
| B23 | IRQ5 | Out | JP1 option |
| B1, B10 | GND | Power | Ground |
| B3, B29 | +5V | Power | VCC |

Note: ISA pin numbering follows standard XT 8-bit convention.

---

## 3. ATF22V10 Wiring on Prototype

Same firmware as plan.md. All pins are wired — some go to real signals, others to fixed levels.

| ATF22V10 Pin | Signal | Prototype Connection |
|---|---|---|
| 1 | A0 | ISA bus A0 |
| 2 | A2 | ISA bus A2 |
| 3 | A3 | ISA bus A3 |
| 4 | A4 | ISA bus A4 |
| 5 | A5 | ISA bus A5 |
| 6 | A6 | ISA bus A6 |
| 7 | A7 | ISA bus A7 |
| 8 | A8 | ISA bus A8 |
| 9 | A9 | ISA bus A9 |
| 10 | IOR# | ISA bus IOR# (input to PLD) |
| 11 | IOW# | ISA bus IOW# (input to PLD) |
| 12 | GND | Ground |
| 13 | AEN | ISA bus AEN (DMA indicator) |
| **14** | **COM1_CS#** | **No connection** (output floats, no COM1 chip) |
| **15** | **COM2_CS#** | **No connection** (output floats, no COM2 chip) |
| **16** | **PRN_CS#** | **No connection** (output floats, no PRN chip) |
| **17** | **RTC_WR#** | **DS12885 pin 15 (WR# in Intel mode)** |
| **18** | **BUF_EN#** | **74HCT245 pin 19 (G#)** |
| **19** | **RTC_AS** | **DS12885 pin 14 (AS)** |
| **20** | **RTC_DS#** | **DS12885 pin 17 (DS# in Intel mode)** |
| 21 | J_COM1 | Wire directly to GND (no COM1) |
| 22 | J_COM2 | Wire directly to GND (no COM2) |
| 23 | J_PRN | Wire directly to GND (no PRN) |
| 24 | VCC | +5V |

IOR# and IOW# are on dedicated input pins 10–11. All three address jumpers
(J_COM1, J_COM2, J_PRN) are grouped on adjacent I/O pins 21–23, wired to GND
on this prototype board. A0 and A2 are on dedicated input pins 1–2 for compact
address bus routing; AEN is on I/O pin 13 (configured as input). The PLD
generates qualified RTC_WR#
and RTC_DS# strobes — DS12885 CS# is tied to GND (always selected). BUF_EN#
activates whenever any device address range is on the bus.

---

## 4. DS12885 Wiring (DIP-24, Intel Mode)

| DS12885 Pin | Name | Prototype Connection |
|---|---|---|
| 1 | MOT | No connection (internal 20k pull-down → Intel mode) |
| 2 | X1 | Y1 crystal leg 1 |
| 3 | X2 | Y1 crystal leg 2 |
| 4 | AD0 | 74HCT245 pin 18 (B1) |
| 5 | AD1 | 74HCT245 pin 17 (B2) |
| 6 | AD2 | 74HCT245 pin 16 (B3) |
| 7 | AD3 | 74HCT245 pin 15 (B4) |
| 8 | AD4 | 74HCT245 pin 14 (B5) |
| 9 | AD5 | 74HCT245 pin 13 (B6) |
| 10 | AD6 | 74HCT245 pin 12 (B7) |
| 11 | AD7 | 74HCT245 pin 11 (B8) |
| 12 | GND | Ground |
| 13 | CS | GND (always selected — strobes are PLD-qualified) |
| 14 | AS | ATF22V10 pin 19 (RTC_AS) |
| 15 | WR# | ATF22V10 pin 17 (RTC_WR# — qualified write strobe for 0x71) |
| 16 | GND | Ground (second GND pad) |
| 17 | DS# | ATF22V10 pin 20 (RTC_DS# — qualified data strobe for 0x71) |
| 18 | RESET | VCC (per datasheet: allows power-fail transitions without clearing control registers) |
| 19 | IRQ | R1 (4.7k pull-up to VCC), then to JP1 pin 1 |
| 20 | VBAT | BT1 positive (+3V CR2032) |
| 21 | RCLR | Internal pull-up; 2-pin header to GND for manual CMOS clear (optional on prototype) |
| 22 | N.C. | No connection |
| 23 | SQW | No connection (or route to test point) |
| 24 | VCC | +5V |

---

## 5. 74HCT245 Wiring (DIP-20)

| 74HCT245 Pin | Name | Prototype Connection |
|---|---|---|
| 1 | DIR | ISA bus IOR# |
| 2 | A1 | ISA bus D0 |
| 3 | A2 | ISA bus D1 |
| 4 | A3 | ISA bus D2 |
| 5 | A4 | ISA bus D3 |
| 6 | A5 | ISA bus D4 |
| 7 | A6 | ISA bus D5 |
| 8 | A7 | ISA bus D6 |
| 9 | A8 | ISA bus D7 |
| 10 | GND | Ground |
| 11 | B8 | DS12885 pin 11 (AD7) |
| 12 | B7 | DS12885 pin 10 (AD6) |
| 13 | B6 | DS12885 pin 9 (AD5) |
| 14 | B5 | DS12885 pin 8 (AD4) |
| 15 | B4 | DS12885 pin 7 (AD3) |
| 16 | B3 | DS12885 pin 6 (AD2) |
| 17 | B2 | DS12885 pin 5 (AD1) |
| 18 | B1 | DS12885 pin 4 (AD0) |
| 19 | G# | ATF22V10 pin 18 (BUF_EN#) |
| 20 | VCC | +5V |

Direction logic:
- IOR# = 0 → DIR = 0 → B-to-A (RTC drives data to ISA bus)
- IOR# = 1 → DIR = 1 → A-to-B (ISA bus writes to RTC)

---

## 6. RTC IRQ Jumper (JP1)

```
JP1:  1x4 pin header

  Pin 1 ── R1 (4.7k) ── VCC     ← RTC IRQ (open-drain, active low)
           │
           DS12885 pin 19

  Pin 2 ── ISA IRQ5 (B23)
  Pin 3 ── ISA IRQ6 (B22)       ← not commonly used, good for testing
  Pin 4 ── ISA IRQ7 (B21)

  Jumper wire from Pin 1 to one of Pin 2/3/4 selects the IRQ line.
  Leave open if no IRQ needed (RTC still works for polled access).
```

---

## 7. Circuit Diagram

```
═══════════════════════════ ISA 8-bit Bus Edge Connector (J1) ══════════════════
  D0─D7          A0  A3─A9      IOR#   IOW#   AEN             IRQ5  IRQ6  IRQ7
   │              │   │           │      │      │               │     │     │
   │   ┌──────────┤   │           │      │      │               │     │     │
   │   │          │   │           │      │      │               │     │     │
   │   │          │   │           │      │      │               │     │     │
═══╪═══╪══════════╪═══╪═══════════╪══════╪══════╪═══════════════╪═════╪═════╪════
   │   │          │   │           │      │      │               │     │     │
   │   │          │   │           │      │      │             ┌─┴──┬──┴──┬──┘
   │   │          │   │           │      │      │             │ JP1│     │
   │   │          │   │           │      │      │             │2  3│  4  │
   │   │          │   │           │      │      │             └─┬──┴──┬──┘
   │   │          │   │           │      │      │               └──┬──┘
   │   │          │   │           │      │      │                 │1
   │   │          │   │           │      │      │      │          │
   │   │          │   │           │      │      │      │      R1 4.7k
   │   │          │   │           │      │      │      │          │
   │   │          │   │           │      │      │      │         VCC
   │   │          │   │           │      │      │      │
   │   │  ┌───────┘   │           │      │      │      │
   │   │  │  ┌────────┘           │      │      │      │
   │   │  │  │                    │      │      │      │
   │   │  │  │    ┌───────────────┤      │      │      │
   │   │  │  │    │    ┌──────────┼──────┤      │      │
   │   │  │  │    │    │          │      │      │      │
   │   │  │  │    │    │          │      │      │      │
   │   │  │  │    │    │          │      │      │      │
   ▼   ▼  ▼  ▼    ▼    ▼          ▼      ▼      ▼      ▼
┌──────────────────────────────────────────────────────────────────────────┐
│                                                                          │
│  ┌────────────────────┐   ┌──────────────────────┐   ┌────────────────┐  │
│  │    U2: 74HCT245    │   │    U1: ATF22V10      │   │  U3: DS12885   │  │
│  │    (DIP-20)        │   │    (DIP-24)          │   │  (DIP-24)      │  │
│  │                    │   │                      │   │                │  │
│  │ ISA Side:          │   │ Inputs:              │   │ Pin 1  MOT  NC│  │
│  │ pin 2  A1 ── D0    │   │ pin 1  AEN ── AEN   │   │ pin 2  X1 ──┐ │  │
│  │ pin 3  A2 ── D1    │   │ pin 2  A0  ── A0    │   │ pin 3  X2 ──┤ │  │
│  │ pin 4  A3 ── D2    │   │ pin 3  A3  ── A3    │   │        Y1   │ │  │
│  │ pin 5  A4 ── D3    │   │ pin 4  A4  ── A4    │   │       32768Hz│ │  │
│  │ pin 6  A5 ── D4    │   │ pin 5  A5  ── A5    │   │              │ │  │
│  │ pin 7  A6 ── D5    │   │ pin 6  A6  ── A6    │   │ pin 4  AD0 ─┼─┼──pin 18 B1
│  │ pin 8  A7 ── D6    │   │ pin 7  A7  ── A7    │   │ pin 5  AD1 ─┼─┼──pin 17 B2
│  │ pin 9  A8 ── D7    │   │ pin 8  A8  ── A8    │   │ pin 6  AD2 ─┼─┼──pin 16 B3
│  │                    │   │ pin 9  A9  ── A9    │   │ pin 7  AD3 ─┼─┼──pin 15 B4
│  │ Card Side:         │   │ pin 10 IOR ── IOR#    │ pin 8  AD4 ─┼─┼──pin 14 B5
│  │ pin 18 B1 ── AD0   │   │ pin 11 IOW ── IOW#    │ pin 9  AD5 ─┼─┼──pin 13 B6
│  │ pin 17 B2 ── AD1   │   │ pin 13 NC             │   │ pin 10 AD6 ─┼─┼──pin 12 B7
│  │ pin 16 B3 ── AD2   │   │                      │   │ pin 11 AD7 ─┼─┼──pin 11 B8
│  │ pin 15 B4 ── AD3   │   │ pin 23 JP  ─┤10k├─GND  │   │              │ │  │
│  │ pin 14 B5 ── AD4   │   │ pin 22 J2  ─┤10k├─GND  │ pin 12 GND──┼─┼──GND
│  │ pin 13 B6 ── AD5   │   │ pin 21 J1  ─┤10k├─GND  │ pin 13 CS ──┼─┼──GND
│  │ pin 12 B7 ── AD6   │   │ pin 20 RTC_DS#────────┼───┤►pin 17 DS#   │ │
│  │ pin 11 B8 ── AD7   │   │ Outputs:             │   │ pin 14 AS   │ │        │
│  │                    │   │ pin 14 COM1_CS#  NC │   │ pin 15 WR#  │ │        │
│  │ pin 1  DIR ── IOR# │   │ pin 15 COM2_CS#  NC │   │ pin 16 GND──┼─┼──GND   │
│  │ pin 19 G#  ────────┼───┤ pin 16 PRN_CS#    NC │   │ pin 17 DS#   │ │        │
│  │ pin 10 GND ── GND  │   │ pin 17 RTC_WR# ──────┼───┤►pin 15 WR#  │ │        │
│  │ pin 20 VCC ── VCC  │   │ pin 18 BUF_EN# ─────┼───┤►pin 19 G#   │ │        │
│  │                    │   │ pin 19 RTC_AS  ──────┼───┤►pin 14 AS   │ │        │
│  └────────────────────┘   │ pin 20 RTC_DS#  ─────┼───┤►pin 17 DS#   │ │        │
│                           │                      │   │ pin 18 RST──┼─┼─VCC    │
│                           │ pin 12 GND ── GND    │   │ pin 19 IRQ──┼─┼─ JP1   │
│                           │ pin 24 VCC ── VCC    │   │ pin 20 VBAT─┼─┼─ BT1+  │
│                           │                      │   │ pin 23 SQW  NC│        │ │
│                           └──────────────────────┘   │ pin 24 VCC──┼─┼──VCC   │ │
│                                                      │             │ │        │ │
│                                                      └─────────────┘ │        │ │
│                                                                      │        │ │
│  Bypass capacitors: C1 (100nF) U1 VCC-GND                           │        │ │
│                     C2 (100nF) U2 VCC-GND                           │        │ │
│                     C3 (100nF) U3 VCC-GND                           │        │ │
│                     C4 (10uF)  bulk VCC-GND near ISA connector      │        │ │
│                                                                      │        │ │
└──────────────────────────────────────────────────────────────────────┘        │ │
                                                                                │ │
                            (arrows show signal flow, all active connections)   │ │
```

### Detailed Net List

```
Net Name        From                    To
────────────────────────────────────────────────────────
ISA_D0          ISA D0 (A9)             U2 pin 2 (A1)
ISA_D1          ISA D1 (A8)             U2 pin 3 (A2)
ISA_D2          ISA D2 (A7)             U2 pin 4 (A3)
ISA_D3          ISA D3 (A6)             U2 pin 5 (A4)
ISA_D4          ISA D4 (A5)             U2 pin 6 (A5)
ISA_D5          ISA D5 (A4)             U2 pin 7 (A6)
ISA_D6          ISA D6 (A3)             U2 pin 8 (A7)
ISA_D7          ISA D7 (A2)             U2 pin 9 (A8)
CARD_D0         U2 pin 18 (B1)          U3 pin 4 (AD0)
CARD_D1         U2 pin 17 (B2)          U3 pin 5 (AD1)
CARD_D2         U2 pin 16 (B3)          U3 pin 6 (AD2)
CARD_D3         U2 pin 15 (B4)          U3 pin 7 (AD3)
CARD_D4         U2 pin 14 (B5)          U3 pin 8 (AD4)
CARD_D5         U2 pin 13 (B6)          U3 pin 9 (AD5)
CARD_D6         U2 pin 12 (B7)          U3 pin 10 (AD6)
CARD_D7         U2 pin 11 (B8)          U3 pin 11 (AD7)
ISA_A0          ISA A0 (A31)            U1 pin 1
ISA_A2          ISA A2 (A29)            U1 pin 2
ISA_A3          ISA A3 (A28)            U1 pin 3
ISA_A4          ISA A4 (A27)            U1 pin 4
ISA_A5          ISA A5 (A26)            U1 pin 5
ISA_A6          ISA A6 (A25)            U1 pin 6
ISA_A7          ISA A7 (A24)            U1 pin 7
ISA_A8          ISA A8 (A23)            U1 pin 8
ISA_A9          ISA A9 (A22)            U1 pin 9
ISA_AEN         ISA AEN (A11)           U1 pin 13
ISA_IOR#        ISA IOR# (B14)          U2 pin 1 (DIR), U1 pin 10 (IOR)
ISA_IOW#        ISA IOW# (B13)          U1 pin 11 (IOW)
RTC_RESET       VCC                     U3 pin 18 (RESET)
RTC_WR#         U1 pin 17               U3 pin 15 (WR#)
BUF_EN#         U1 pin 18               U2 pin 19 (G#)
RTC_AS          U1 pin 19               U3 pin 14 (AS)
RTC_DS#         U1 pin 20               U3 pin 17 (DS#)
RTC_CS#         GND                     U3 pin 13 (CS)
RTC_IRQ         U3 pin 19               R1 (4.7k to VCC), JP1 pin 1
VCC             ISA +5V                 U1-24, U2-20, U3-24, R pull-ups, C bypass
GND             ISA GND                 U1-12, U2-10, U3-12, U3-16, R pull-downs, C bypass
VBAT            BT1 (+)                 U3 pin 20
```

---

## 8. Bus Cycle Walkthrough (Prototype Verification)

### Test 1: Write RTC Address Register (OUT 70h, value)

```
Step  ISA Bus                 ATF22V10           74HCT245         DS12885
────  ────────────────────    ─────────────────  ────────────────  ──────────────
  1   CPU drives A0=0,        AEN=0              (waiting)         CS=GND (always
      A3-A9 = 0001110                                              selected)
      AEN=0

  2   PLD decodes             BUF_EN# → LOW      G# goes LOW      WR# HIGH (idle)
      port 0x70               RTC_AS still LOW   (buffer on)      DS# HIGH (idle)
                              RTC_WR# HIGH
                              RTC_DS# HIGH
                              (IOW#/IOR# not
                               yet active)

  3   CPU drives data         (stable)           DIR=1 (IOR#=1)   AS still LOW
      on D0-D7                                   A→B: ISA→card    data on AD0-7

  4   IOW# goes LOW           RTC_AS → HIGH      (stable)          AS goes HIGH
                              (addr match +                        → latch opens
                               A0=0 + IOW#)                       (transparent)
                              RTC_WR# stays HIGH                   WR# stays HIGH
                              (A0=0, no data                      (no data write)
                               write)

  5   IOW# returns HIGH       RTC_AS → LOW       (stable)          AS falls →
                                                                   address latch
                                                                   FREEZES,
                                                                   capturing
                                                                   reg addr.

  6   Bus cycle ends           BUF_EN#→HIGH      G#→HIGH          Latch frozen,
      Between cycles,          RTC_AS stays LOW                    address safe.
      RTC_AS stays LOW —       (addr mismatch)                     WR#/DS# idle.
      no corruption possible
```

### Test 2: Read RTC Data Register (IN AL, 71h)

```
Step  ISA Bus                 ATF22V10           74HCT245         DS12885
────  ────────────────────    ─────────────────  ────────────────  ──────────────
  1   CPU drives A0=1,        AEN=0              (waiting)         CS=GND (always
      A3-A9 = 0001110                                              selected)
      AEN=0

  2   PLD decodes             BUF_EN# → LOW      G# goes LOW      WR# HIGH (idle)
      port 0x71               RTC_AS stays LOW   (buffer on)      DS# HIGH (idle)
                              (A0=1)

  3   IOR# goes LOW           RTC_DS# → LOW       DIR=0 (IOR#=0)   DS# goes LOW
                              (addr match +      B→A: card→ISA    → RTC drives
                               A0=1 + IOR#)                        data onto
                                                                   AD0-AD7

  4   Data flows:             (stable)           AD0-7 → D0-7     (driving bus)
      DS12885 → 74245 B→A → ISA D0-D7
      CPU reads D0-D7

  5   IOR# returns HIGH       RTC_DS# → HIGH      DIR=1, G#→HIGH   DS# goes HIGH
      Bus cycle ends           BUF_EN#→HIGH                        bus released
```

### Test 3: Write RTC Data Register (OUT 71h, value)

```
Step  ISA Bus                 ATF22V10           74HCT245         DS12885
────  ────────────────────    ─────────────────  ────────────────  ──────────────
  1   CPU drives A0=1,        AEN=0              (waiting)         CS=GND
      A3-A9 = 0001110
      AEN=0

  2   PLD decodes             BUF_EN# → LOW      G# goes LOW      WR# HIGH
      port 0x71               RTC_AS stays LOW   (buffer on)      DS# HIGH
                              (A0=1)

  3   CPU drives write data   (stable)           DIR=1 (IOR#=1)   (waiting)
      on D0-D7                                   A→B: ISA→card

  4   IOW# goes LOW           RTC_WR# → LOW       (stable)          WR# goes LOW
                              (addr match +                        (write mode)
                               A0=1 + IOW#)

  5   IOW# returns HIGH       RTC_WR# → HIGH      (stable)          WR# rising edge
                                                                   → DS12885
                                                                   latches data
                                                                   from AD0-AD7

  6   Bus cycle ends           BUF_EN#→HIGH      G#→HIGH          Write complete
```

---

## 9. Software Test Program (DOS DEBUG)

```
; Set register address to 0x00 (seconds)
O 70 00

; Read seconds value
I 71
; Should return BCD seconds (00-59) or binary depending on DM bit

; Read register 0x0A (Register A) - check oscillator
O 70 0A
I 71
; Bit 7 (UIP) toggles once per second; bits 6-4 should be 010 (DV=010 = oscillator on)
; Expected value when running: 0x26 (DV=010, RS=0110 = 1024 Hz default)

; Write Register B to set 24-hour BCD mode
O 70 0B
O 71 02
; Sets 24-hour mode (bit 1=1), BCD (bit 2=0)

; Verify Register D (valid RAM bit)
O 70 0D
I 71
; Bit 7 should be 1 if battery is good (VRT=1)
```

---

## 10. Prototype Test Checklist

- [ ] Power: verify +5V on U1-24, U2-20, U3-24 and GND continuity
- [ ] No bus contention: with card inserted but before testing, check no data bus
      pins are being driven (74245 G# should be HIGH when no I/O cycle)
- [ ] PLD decode: use logic analyzer on RTC_WR# (U1-17) and RTC_DS# (U1-20) —
      RTC_WR# should pulse LOW only during OUT 71h; RTC_DS# only during IN 71h
- [ ] PLD non-decode: verify COM1_CS#, COM2_CS#, PRN_CS# never go LOW
- [ ] BUF_EN#: should go LOW during port 0x70 and 0x71 access
- [ ] DS12885 CS# (pin 13): verify wired to GND
- [ ] RTC_AS: should pulse HIGH only during IOW# active phase of port 0x70
      write; should stay LOW during port 0x71 access and all non-RTC cycles
- [ ] Direction: verify 74245 DIR follows IOR# correctly
- [ ] RTC read: `I 71` after `O 70 00` returns changing seconds value
- [ ] RTC write: can set time, read back matches
- [ ] Battery backup: remove power, wait, reinsert — time should persist
- [ ] IRQ (optional): program RTC periodic interrupt, verify interrupt fires on selected IRQ

---

## 11. Known Limitations of Prototype

1. **No UART/PRN** — only RTC is testable
2. **PLD outputs 14-16 float** — acceptable since nothing is connected; they are
   driven by the PLD (not tri-stated), so they won't cause issues
3. **Crystal layout matters** — keep Y1 traces short, away from data bus traces,
   with local ground plane under the crystal if possible
4. **ISA bus loading** — single 74HCT245 presents minimal load; no concerns
5. **Battery**: do NOT install CR2032 backwards — no reverse polarity protection
   in this minimal design (consider adding a diode in the full board)

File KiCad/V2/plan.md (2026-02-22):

# ISA8 LPT COM RTC - Implementation Plan

## 1. ISA Bus Signals Used

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

## 2. I/O Port Address Map

| Device | Option A (Default) | Option B | Address Range Size |
|---|---|---|---|
| COM1 | 0x3F8-0x3FF | 0x2F8-0x2FF | 8 bytes |
| COM2 | 0x3E8-0x3EF | 0x2E8-0x2EF | 8 bytes |
| PRN (LPT1) | 0x378-0x37F | 0x278-0x27F (LPT2) | 8 bytes |
| RTC | 0x70-0x71 | (fixed) | 2 bytes |

### Address Bit Patterns (A9..A0)

```
COM1 @ 0x3F8:  11 1111 1xxx    COM1 @ 0x2F8:  10 1111 1xxx
COM2 @ 0x3E8:  11 1110 1xxx    COM2 @ 0x2E8:  10 1110 1xxx
PRN   @ 0x378:  11 0111 1xxx    PRN   @ 0x278:  10 0111 1xxx
RTC   @ 0x070:  00 0111 00 0x   (fixed, no jumper; A2 checked by PLD)
```

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

## 3. Jumper Design

### 3.1 Jumper Inputs to ATF22V10

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

**Approach: one jumper bit per device fed into the PLD.**

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

These jumper signals connect directly to ATF22V10 inputs. The PLD equations incorporate them.

### 3.2 IRQ Selection Jumpers

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

For the RTC IRQ (4 choices: IRQ2/9, IRQ5, IRQ6, IRQ7), use a 1×5 pin header:
```
Pin 1: RTC_IRQ_OUT (from Q1 collector via R4, active high — inverted from DS12885)
Pin 2: IRQ2 (= IRQ9 on AT-class machines via cascade)
Pin 3: IRQ5
Pin 4: IRQ6
Pin 5: IRQ7
```
A single jumper wire connects Pin 1 to one of Pins 2–5.

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

### 3.3 Jumper Summary Table

| Jumper | Type | Pins | Function |
|---|---|---|---|
| JP_COM1_ADDR | 3-pin header | 1=VCC, 2=J_COM1, 3=GND | Cap 1-2: 0x3F8 (COM1), Cap 2-3: 0x2F8 (COM2) |
| JP_COM1_IRQ | 3-pin header | 1=IRQ4, 2=COM1_IRQ, 3=IRQ3 | Select IRQ |
| JP_COM2_ADDR | 3-pin header | 1=VCC, 2=J_COM2, 3=GND | Cap 1-2: 0x3E8 (COM3), Cap 2-3: 0x2E8 (COM4) |
| JP_COM2_IRQ | 3-pin header | 1=IRQ4, 2=COM2_IRQ, 3=IRQ3 | Select IRQ |
| JP_PRN_ADDR | 3-pin header | 1=VCC, 2=J_PRN, 3=GND | Cap 1-2: 0x378 (LPT1), Cap 2-3: 0x278 (LPT2) |
| JP_PRN_IRQ | 3-pin header | 1=IRQ7, 2=PRN_IRQ, 3=IRQ5 | Select IRQ |
| JP_RTC_IRQ | 1×5 header | 1=RTC_IRQ_OUT, 2=IRQ2/9, 3=IRQ5, 4=IRQ6, 5=IRQ7 | Jumper wire Pin1 to one of Pin2–5 |

### 3.4 Device Enable/Disable

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

**Address jumper wiring (3-pin header):**

All three address jumpers (JP_COM1_ADDR, JP_COM2_ADDR, JP_PRN_ADDR) follow the same scheme:

```
  Pin 1 = VCC
  Pin 2 = J_xxx (to PLD input, 10k pull-down to GND)
  Pin 3 = GND
```
- Cap on 1-2: signal = HIGH → Option A (higher address)
- Cap on 2-3: signal = LOW → Option B (lower address)
- No cap: signal = LOW (pull-down) → Option B (default)

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

## 4. ATF22V10 Pin Assignment

### 4.1 ATF22V10C Pinout (24-pin DIP/PLCC)

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

### 4.2 Pin Assignment

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

## 5. DS12885 RTC Interface to ISA Bus

### 5.1 Bus Mode Selection

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

### 5.2 Signal Connections

| DS12885 Pin | Signal | ISA / Board Connection |
|---|---|---|
| MOT | Bus mode | Leave unconnected (pulled low internally → Intel mode) |
| AD0-AD7 | Mux Addr/Data | Connected to card-side data bus (74245 B-side). These are shared address AND data lines. |
| CS | Chip select | Tie to GND (always selected — access is controlled by PLD-qualified strobes) |
| AS | Address strobe | RTC_AS from ATF22V10 — active-high, gated with IOW# and address decode (see below) |
| DS# | Data strobe | RTC_DS# from ATF22V10 — active-low, fires only during IN from port 0x71 |
| WR# | Write strobe | RTC_WR# from ATF22V10 — active-low, fires only during OUT to port 0x71 |
| RESET | Reset | Tie to VCC (per datasheet: allows power-fail transitions without clearing control registers) |
| IRQ | Interrupt out | Open-drain, inverted via NPN transistor (Q1) to active-high; output via R4 (330Ω) to jumper JP_RTC_IRQ selecting IRQ2/9, IRQ5, IRQ6, or IRQ7 (see Section 6) |
| SQW | Square wave | Leave unconnected or route to test point |
| X1, X2 | Crystal | 32.768 kHz crystal (Y1) |
| VCC | Power | +5V from ISA bus |
| VBAT | Backup battery | CR2032 (3V) via battery holder |
| RCLR | RAM clear | Tie to VCC via 10k pull-up (or add a push-button to GND for manual RAM clear) |

### 5.3 Multiplexed Address/Data Bus — Address Latch Mechanism

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

### 5.4 Intel Mode Timing Summary

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

### 5.5 Address Latch Integrity Between Bus Cycles

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

## 6. RTC IRQ Polarity Inversion

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

### Circuit

RTC IRQ Polarity Inversion — NPN Inverter

### Operation

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

### Component Values

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

### Contention Protection

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

### Signal Integrity

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

### Behavioral Consistency with UART/PRN IRQ Outputs

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

## 7. 74245 Bus Buffer

### 7.1 Connections

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

### 7.2 Direction Logic

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

### 7.3 Enable Logic

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

## 8. Bill of Materials (Logic Section)

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

## 9. Schematic Block Diagram

```
                    ISA 8-bit Bus
                    ═══════════════════════════════════
                    │D0-D7  A0-A9  IOR# IOW# AEN  IRQ3-7│
                    │   │     │      │    │    │      │       │  │
                    │   │     │      │    │    │      │       │  │
                ┌───┼───┼─────┼──────┼────┼────┼──────┼───────┼──┤
                │   │   │     │      │    │    │      │       │  │
    ┌───────────┤   │   │     │      │    │    │      │       │  │
    │  74HCT245 │   │   │     │      │    │    │      │       │  │
    │  ┌────┐   │   │   │     │      │    │    │      │       │  │
    │  │A  B│◄──┼───┘   │     │      │    │    │      │       │  │
    │  │    │───┼──┐    │     │      │    │    │      │       │  │
    │  │DIR │◄──┼──┼────┼─────┼──────┘    │    │      │       │  │
    │  │ G# │◄──┼──┼──┐ │     │            │    │      │       │  │
    │  └────┘   │  │  │ │     │            │    │      │       │  │
    └───────────┘  │  │ │     │            │    │      │       │  │
                   │  │ │     │            │    │      │       │  │
    ┌──────────────┼──┼─┼─────┼────────────┼────┼──────┼───────┼──┤
    │ ATF22V10     │  │ │     │            │    │      │       │  │
    │              │  │ │     │            │    │      │       │  │
    │ A0-A9,AEN ◄──┼──┼─┼─────┘            │    │      │       │  │
    │ J_COM1/2 ◄──┼──┼─┼── Jumpers        │    │      │       │  │
    │ J_PRN     ◄──┼──┼─┼── Jumpers        │    │      │       │  │
    │              │  │ │                   │    │      │       │  │
    │ COM1_CS# ───┼──┼─┼──► COM1 CS2     │    │      │       │  │
    │ COM2_CS# ───┼──┼─┼──► COM2 CS2     │    │      │       │  │
    │ PRN_CS#   ───┼──┼─┼──► PRN CS        │    │      │       │  │
    │ RTC_WR#  ───┼──┼─┼──► DS12885 WR#  │    │      │       │  │
    │ BUF_EN#   ───┼──┘ │                  │    │      │       │  │
    │ RTC_AS   ───┼────►│  DS12885 AS     │    │      │       │  │
    │ RTC_DS#  ───┼────►│  DS12885 DS#    │    │      │       │  │
    │ IOR# ◄──────┼─────┼──────────────────┘    │      │       │  │
    └──────────────┘     │                  │    │      │       │  │
                         │                  │    │      │       │  │
                Card Data Bus (from 74245 B-side)│      │       │  │
                   ══════╪══════════════════╪════╪══════╪═══════╪══╪
                         │                  │    │      │       │  │
              ┌──────┐ ┌─┴────┐ ┌──────┐ ┌─┴────┴──┐   │       │  │
              │COM1  │ │COM2  │ │ PRN  │ │ DS12885 │   │       │  │
              │16450 │ │16450 │ │82C11 │ │  RTC    │   │       │  │
              │      │ │      │ │      │ │CS#=GND  │   │       │  │
              │      │ │      │ │      │ │WR#=PLD │   │       │  │
              │      │ │      │ │      │ │RD#=PLD │   │       │  │
              └──┬───┘ └──┬───┘ └──┬───┘ └────┬────┘   │       │  │
                 │IRQ     │IRQ    │IRQ        │IRQ     │       │  │
                 │        │       │           │        │       │  │
              [JP_IRQ] [JP_IRQ] [JP_IRQ]  [JP_IRQ]    │       │  │
                 └────────┴───────┴───────────┴────────┘       │  │
                                                    To ISA IRQ lines
```

## 10. Implementation Steps

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

## 11. Design Notes and Caveats

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

## 12. ATF22V10 Chip Logic — Detailed Analysis

### 12.1 XNOR Address Matching

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

### 12.2 PLD Equations

**COM1** (0x3F8 or 0x2F8 — fixed bits: A9=1, A7–A3=11111):

```
/COM1 = /AEN * A9 *  A8 *  JCOM1 * A7 * A6 * A5 * A4 * A3
       + /AEN * A9 * /A8 * /JCOM1 * A7 * A6 * A5 * A4 * A3
```

**COM2** (0x3E8 or 0x2E8 — same as COM1 but A4=0):

```
/COM2 = /AEN * A9 *  A8 *  JCOM2 * A7 * A6 * A5 * /A4 * A3
       + /AEN * A9 * /A8 * /JCOM2 * A7 * A6 * A5 * /A4 * A3
```

**PRN** (0x378 or 0x278 — same structure but A7=0):

```
/PRN = /AEN * A9 *  A8 *  JPRN * /A7 * A6 * A5 * A4 * A3
     + /AEN * A9 * /A8 * /JPRN * /A7 * A6 * A5 * A4 * A3
```

**RTC Write Strobe** (port 0x71 write — DS12885 WR#, 1 product term):

```
/RTC_WR = /AEN * /IOW * A0 * /A2 * /A9 * /A8 * /A7 * A6 * A5 * A4 * /A3
```

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

```
/BUFEN = /AEN * A9 *  A8 *  JCOM1 * A7 * A6 * A5 * A4 * A3
       + /AEN * A9 * /A8 * /JCOM1 * A7 * A6 * A5 * A4 * A3
       + /AEN * A9 *  A8 *  JCOM2 * A7 * A6 * A5 * /A4 * A3
       + /AEN * A9 * /A8 * /JCOM2 * A7 * A6 * A5 * /A4 * A3
       + /AEN * A9 *  A8 *  JPRN   * /A7 * A6 * A5 * A4 * A3
       + /AEN * A9 * /A8 * /JPRN   * /A7 * A6 * A5 * A4 * A3
       + /AEN * /A2 * /A9 * /A8 * /A7 * A6 * A5 * A4 * /A3
```

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

```
RTC_AS = /AEN * /IOW * /A0 * /A2 * /A9 * /A8 * /A7 * A6 * A5 * A4 * /A3
```

**RTC Data Strobe** (port 0x71 read — DS12885 DS#, 1 product term):

```
/RTC_DS = /AEN * /IOR * A0 * /A2 * /A9 * /A8 * /A7 * A6 * A5 * A4 * /A3
```

### 12.3 Product Term Budget

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

Total: **16 product terms** used, substantial headroom on all pins.

### 12.4 CUPL Source

```cupl
Name     ISA8_DECODE;
PartNo   01;
Date     2026-02-14;
Designer VK;
Company  ;
Assembly ;
Location ;
Device   g22v10;

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

/* Address jumpers on I/O pins (configured as inputs) */
Pin 21 = J_COM1;
Pin 22 = J_COM2;

Pin 23 = J_PRN;

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

/* RTC Data Strobe: drives DS12885 DS# (Intel mode) */
/* Fires during IN from port 0x71 (A0=1, data register access) */
RTC_DS = !AEN & !IOR & A0 & !A2 & !A9 & !A8 & !A7 & A6 & A5 & A4 & !A3;
```

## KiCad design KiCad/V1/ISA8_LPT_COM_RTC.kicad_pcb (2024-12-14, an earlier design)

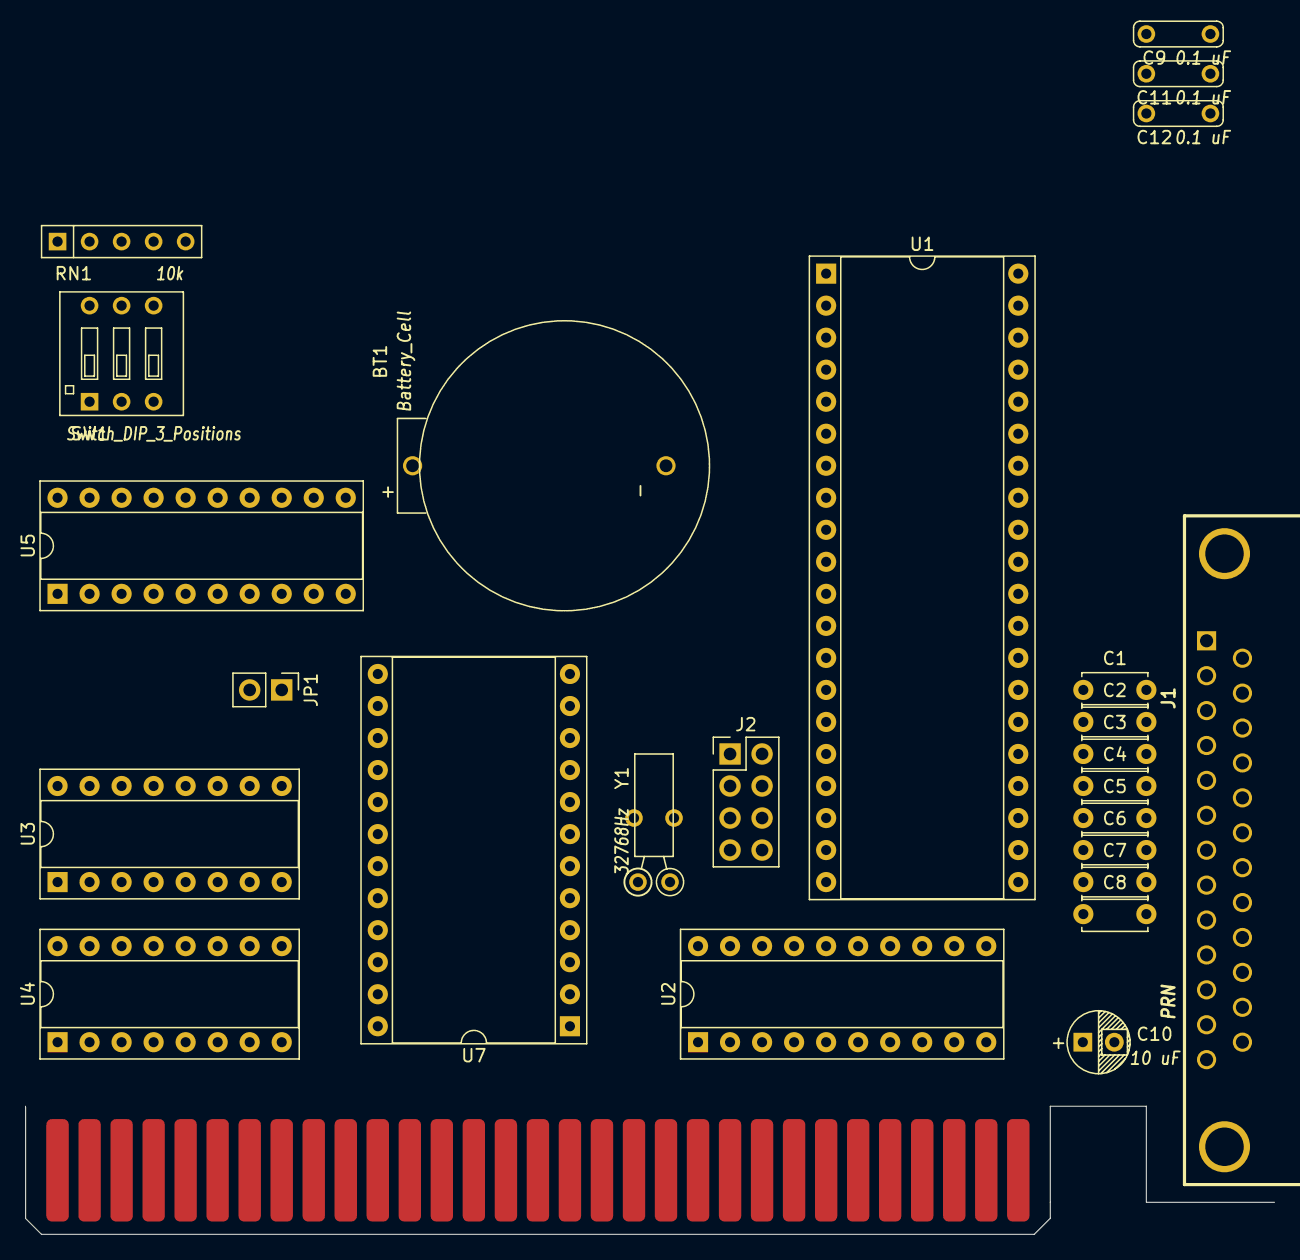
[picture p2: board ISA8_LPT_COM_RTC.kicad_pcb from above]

Board: 2 copper layers, 26 parts (0 on the bottom side), 68 nets, no tracks yet.

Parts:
BT1: Battery_Cell; Battery_Holder_CR2032_Mouser_122-2420-GR
BUS1: BUSPC_DEV; Conn_Edge_PCB_ISA8
C1, C2, C3, C4, C5, C6, C7, C8: 2200pF; C_Disc_D5.0mm_W2.5mm_P5.00mm
C9, C11, C12: 0.1 uF; Cap_Cer_508
C10: 10 uF; Cap_Elec_Radial_5mm_2.5mm
J1: PRN; Conn_Dsub_DB25F
J2: PRN_Conf; PinHeader_2x04_P2.54mm_Vertical
JP1: Clear CMOS; PinHeader_1x02_P2.54mm_Vertical
RN1: 10k; Conn_SIL5
SW1: Switch_DIP_3_Positions
U1: 82C11; DIP-40_W15.24mm_Socket
U2: 74HCT245; DIP-20_W7.62mm_Socket
U3, U4: 74HCT138; DIP-16_W7.62mm_Socket
U5: ATF16V8B; DIP-20_W7.62mm_Socket
U7: DS12885; DIP-24_W15.24mm_Socket
Y1: 32768Hz; Crystal_32K_Horiz

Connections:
/0x278: J2.5, U3.13 (~Y2)
/0x378: J2.7, U3.12 (~Y3)
/A0: BUS1.62 (SA0), U1.38 (A0), U5.1 (I/CLK)
/A1: BUS1.61 (SA1), U1.39 (A1)
/A2: BUS1.60 (SA2), U5.2 (I1)
/A3: BUS1.59 (SA3), U4.1 (A0), U5.3 (I2)
/A4: BUS1.58 (SA4), U3.2 (A1), U5.4 (I3)
/A5: BUS1.57 (SA5), U4.2 (A1), U5.5 (I4)
/A6: BUS1.56 (SA6), U4.3 (A2), U5.6 (I5)
/A7: BUS1.55 (SA7), U3.3 (A2), U5.7 (I6)
/A8: BUS1.54 (SA8), U3.1 (A0), U5.8 (I7)
/A9: BUS1.53 (SA9), U3.6 (E2), U5.9 (I8)
/AEN: BUS1.42 (AEN), U3.4 (~E0), U5.17 (I/O3)
/AS0: RN1.2 (R1), SW1.6, U5.19 (I/O1)
/AS1: RN1.3 (R2), SW1.5, U5.18 (I/O2)
/AS2: RN1.4 (R3), SW1.4, U5.11 (I9/~OE)
/BUSY: J1.11, U1.25 (BUSY)
/D0: BUS1.40 (SD0), U2.18 (B0), U7.4 (AD0)
/D1: BUS1.39 (SD1), U2.17 (B1), U7.5 (AD1)
/D2: BUS1.38 (SD2), U2.16 (B2), U7.6 (AD2)
/D3: BUS1.37 (SD3), U2.15 (B3), U7.7 (AD3)
/D4: BUS1.36 (SD4), U2.14 (B4), U7.8 (AD4)
/D5: BUS1.35 (SD5), U2.13 (B5), U7.9 (AD5)
/D6: BUS1.34 (SD6), U2.12 (B6), U7.10 (AD6)
/D7: BUS1.33 (SD7), U2.11 (B7), U7.11 (AD7)
/IOR: BUS1.14 (IOR), U1.7 (~IOR), U5.13 (I/O7)
/IOW: BUS1.13 (IOW), U1.6 (~IOW), U5.12 (I/O8)
/IRQ6: BUS1.22 (IRQ6), J2.1
/IRQ7: BUS1.21 (IRQ7), J2.3
/PE: J1.12, U1.27 (PE)
/PRN_CS: J2.6, J2.8, U1.18 (~CS), U2.19 (CE)
/PRN_IRQ: J2.2, J2.4, U1.17 (IRQ)
/P_DATA0: C1.2, J1.2, U1.37 (P0)
/P_DATA1: C2.2, J1.3, U1.36 (P1)
/P_DATA2: C3.2, J1.4, U1.35 (P2)
/P_DATA3: C4.2, J1.5, U1.34 (P3)
/P_DATA4: C5.2, J1.6, U1.33 (P4)
/P_DATA5: C6.2, J1.7, U1.32 (P5)
/P_DATA6: C7.2, J1.8, U1.31 (P6)
/P_DATA7: C8.2, J1.9, U1.30 (P7)
/RESET: BUS1.2 (RESET), U1.5 (RST)
/RTCALE: U5.14 (I/O6), U7.14 (AS)
/RTCRD: U5.16 (I/O4), U7.17 (DS)
/RTCWR: U5.15 (I/O5), U7.15 (R/~W)
/SLCK: J1.13, U1.28 (SLCT)
/~ACK: J1.10, U1.26 (~ACK)
/~AUTOFD: J1.14, U1.23 (~AUTOFD)
/~ERROR: J1.15, U1.29 (~ERROR)
/~INIT: J1.16, U1.22 (~INIT)
/~RTC_IRQ: RN1.5 (R4), U7.19 (~IRQ)
/~SCLK: J1.17, U1.21 (~SLCT)
/~STROB: J1.1, U1.24 (~STROB)
GND: BT1.2 (-), BUS1.1 (GND), BUS1.10 (GND), BUS1.31 (GND), C1.1, C2.1, C3.1, C4.1, C5.1, C6.1, C7.1, C8.1, C9.2, C10.2, C11.2, C12.2, J1.18, J1.19, J1.20, J1.21, J1.22, J1.23, J1.24, J1.25, JP1.2 (B), SW1.1, SW1.2, SW1.3, U1.19 (~POE), U1.20 (Vss), U2.10 (GND), U3.8 (GND), U4.4 (~E0), U4.5 (~E1), U4.8 (GND), U5.10 (GND), U7.12 (GND), U7.13 (~CS), U7.16 (GND), Y1.3
unnamed: BT1.1 (+), U7.20 (VBAT)
unnamed: JP1.1 (A), U7.21 (~RCLR)
unnamed: U1.9 (D0), U2.2 (A0)
unnamed: U1.10 (D1), U2.3 (A1)
unnamed: U1.11 (D2), U2.4 (A2)
unnamed: U1.12 (D3), U2.5 (A3)
unnamed: U1.13 (D4), U2.6 (A4)
unnamed: U1.14 (D5), U2.7 (A5)
unnamed: U1.15 (D6), U2.8 (A6)
unnamed: U1.16 (D7), U2.9 (A7)
unnamed: U1.8 (DIR), U2.1 (A->B)
unnamed: U3.5 (~E1), U4.7 (~Y7)
unnamed: U7.2 (X1), Y1.1
unnamed: U7.3 (X2), Y1.2
VCC: BUS1.3 (VCC), BUS1.29 (VCC), C9.1, C10.1, C11.1, C12.1, RN1.1 (common), U1.40 (VDD), U2.20 (VCC), U3.16 (VCC), U4.6 (E2), U4.16 (VCC), U5.20 (VCC), U7.18 (~RESET), U7.24 (VCC)

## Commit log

2024-11-24 Added 82C11 chip and printer interface
    [ISA8_LPT_COM_RTC.kicad_pcb, ISA8_LPT_COM_RTC.kicad_sch]
2024-11-24 Set footprints
    [ISA8_LPT_COM_RTC.kicad_sch]
2024-12-14 Design COM ports
    [ISA8_LPT_COM_RTC.kicad_pcb, ISA8_LPT_COM_RTC.kicad_sch]
2026-02-22 Working prototype.
2026-02-24 Add prototype photo
